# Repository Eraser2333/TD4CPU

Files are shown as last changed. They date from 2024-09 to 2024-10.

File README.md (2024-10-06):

# TD4CPU

淘宝有售噢
[(https://item.taobao.com/item.htm?abbucket=4&id=839364618107)]

套件128比自己打板买零件要划得来噢，10cm*20cm打板5张要75块钱。

成品一个售价248，咨询客服，如果是GitHub或者BiliBili来的有优惠噢。

## 简介
   这一台由74系列数字电路芯片组成的计算机，满足冯·诺依曼提出的计算机的五大基本构件，包括运算器、存储器、输入设备、输出设备和控制器。其核心是一个由10个74芯片构成的4bit CPU，包含了ALU（算术逻辑单元）、ID（指令译码器）、MUX（数据选择器）、PC（程序计数器）、以及寄存器A、B和输出寄存器。
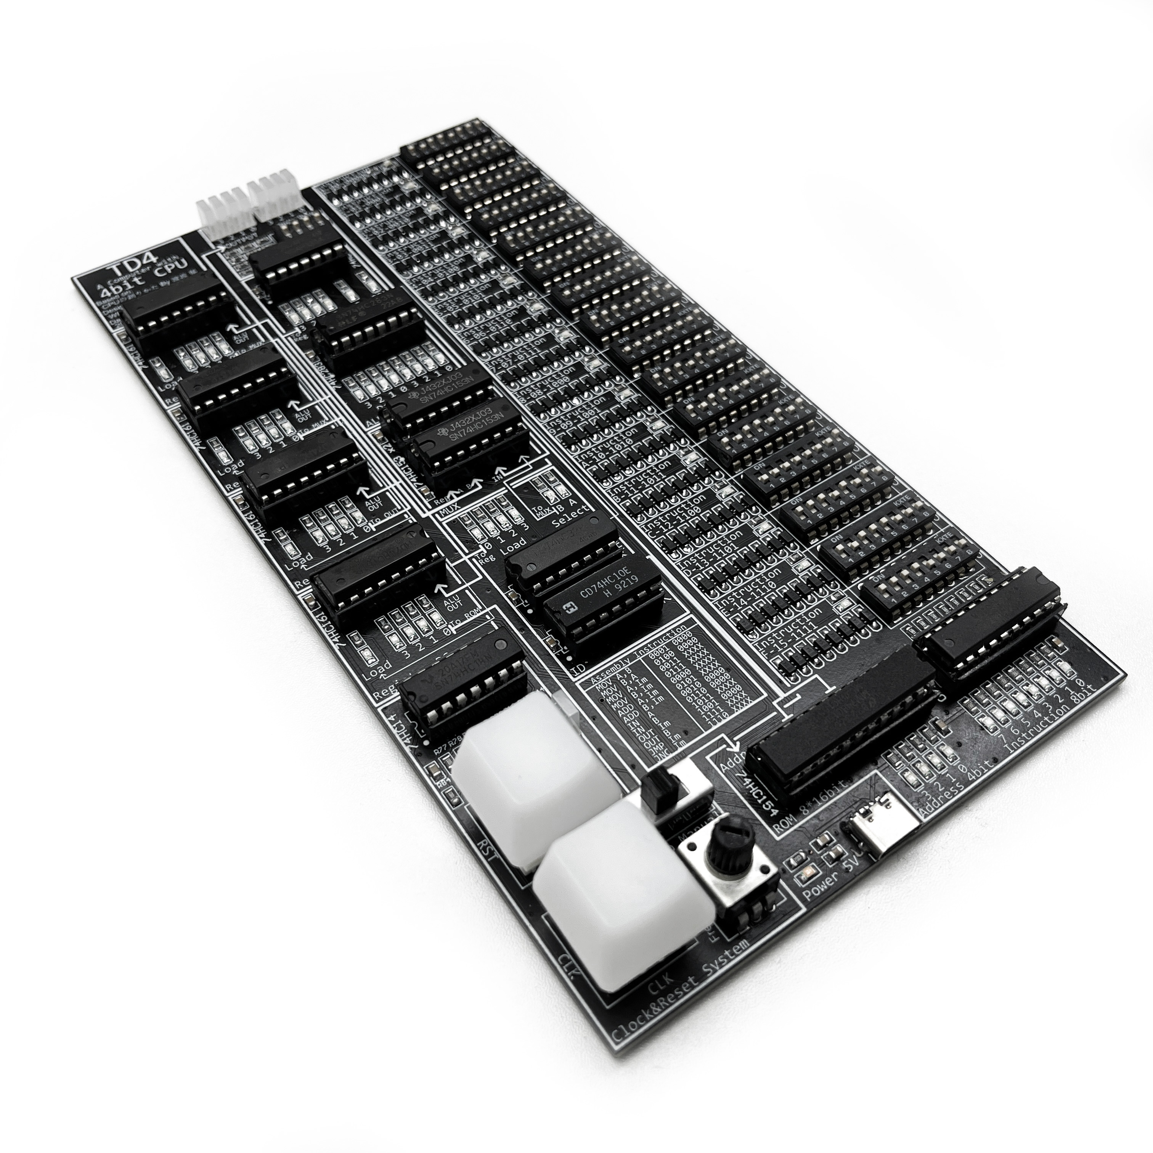
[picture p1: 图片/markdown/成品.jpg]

   与该CPU连接的ROM（只读存储器）用于存储程序，由拨码开关进行编程，可使用12个指令，最多编写16条指令程序。该项目的设计方案来自于日本工程师度波郁（Iku Watanami）的著作《用10个IC轻松介绍CPU设计》，并由来自广州的创元素团队复刻并讲解。由于创元素制复刻的套件不太符合笔者的电路设计审美。故在此基础上制作了更加美观，指示灯清晰的版本。
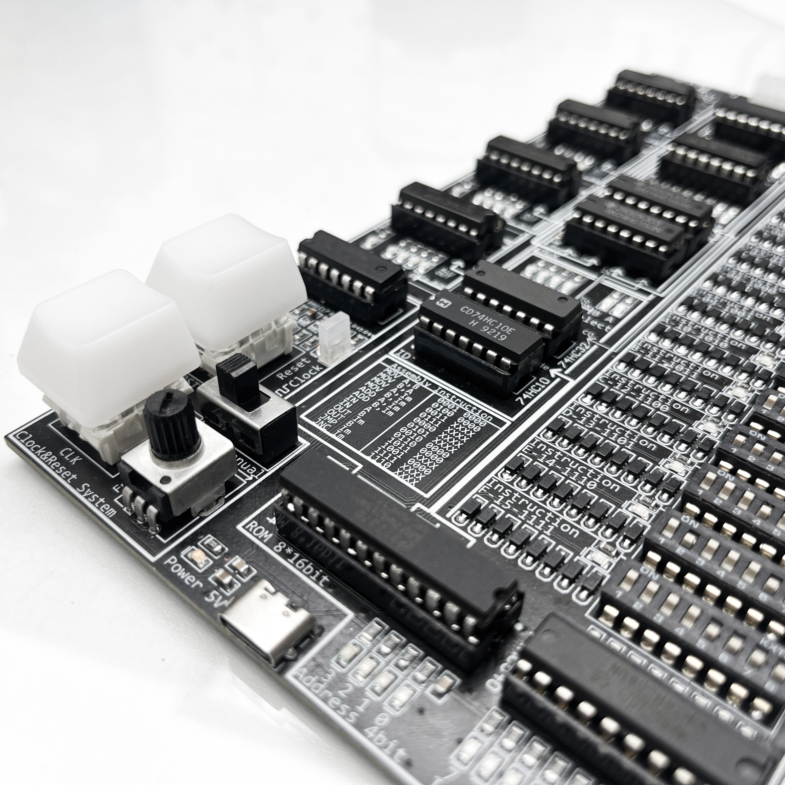
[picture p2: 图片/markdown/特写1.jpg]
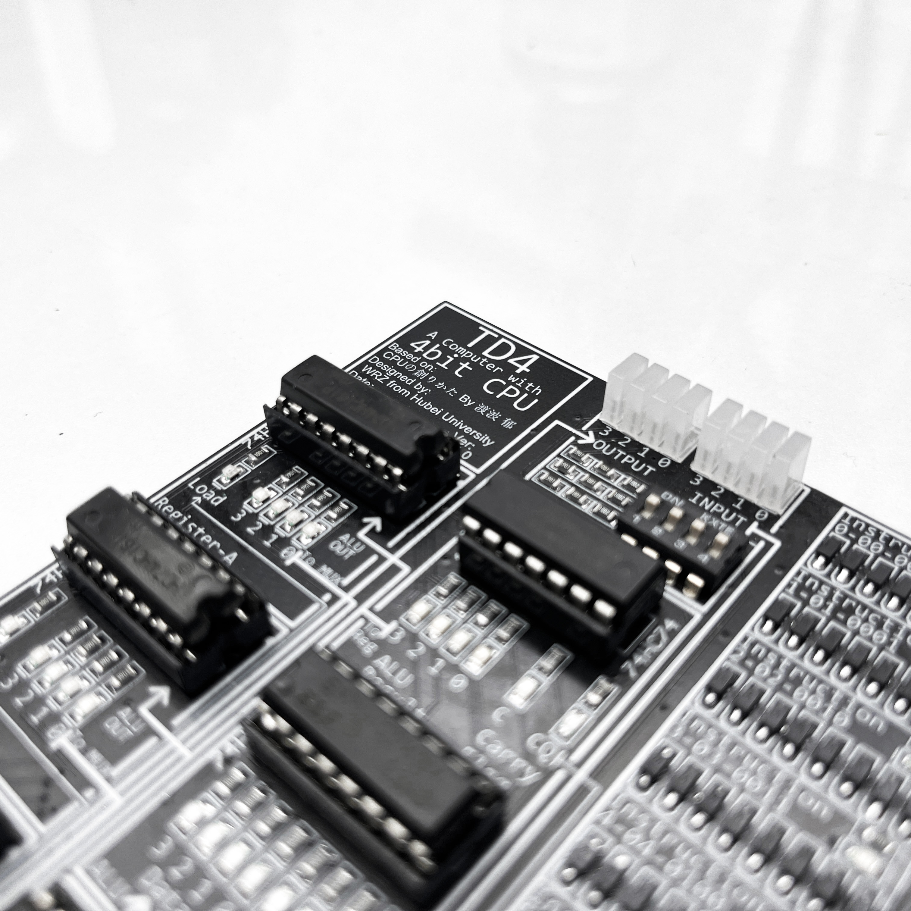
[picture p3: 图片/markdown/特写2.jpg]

<div align=center>
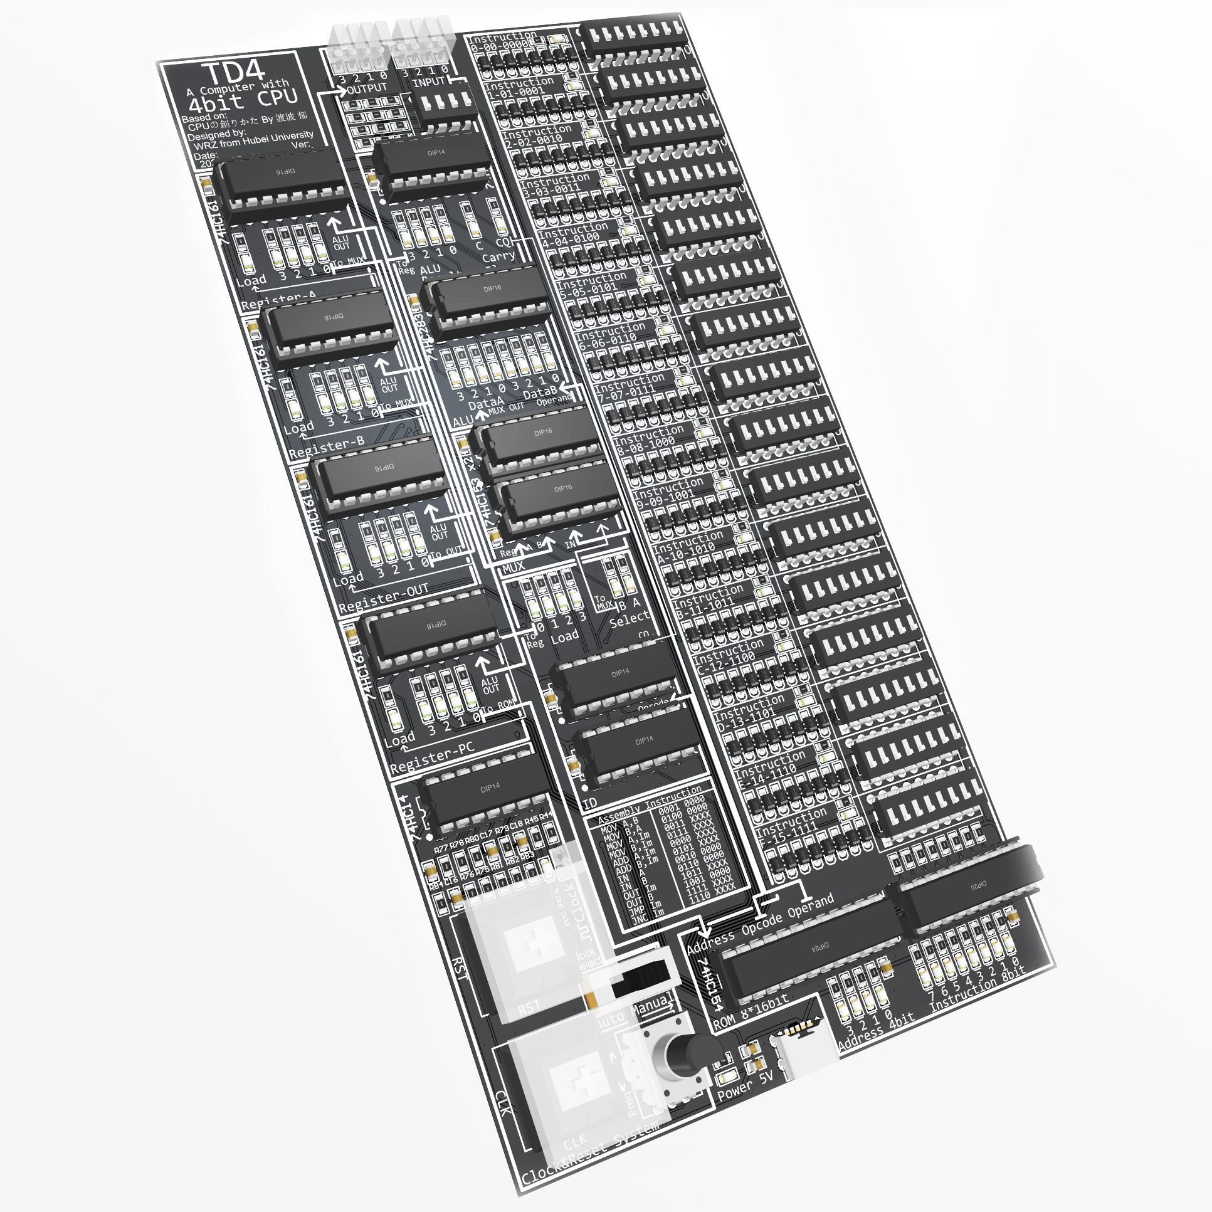
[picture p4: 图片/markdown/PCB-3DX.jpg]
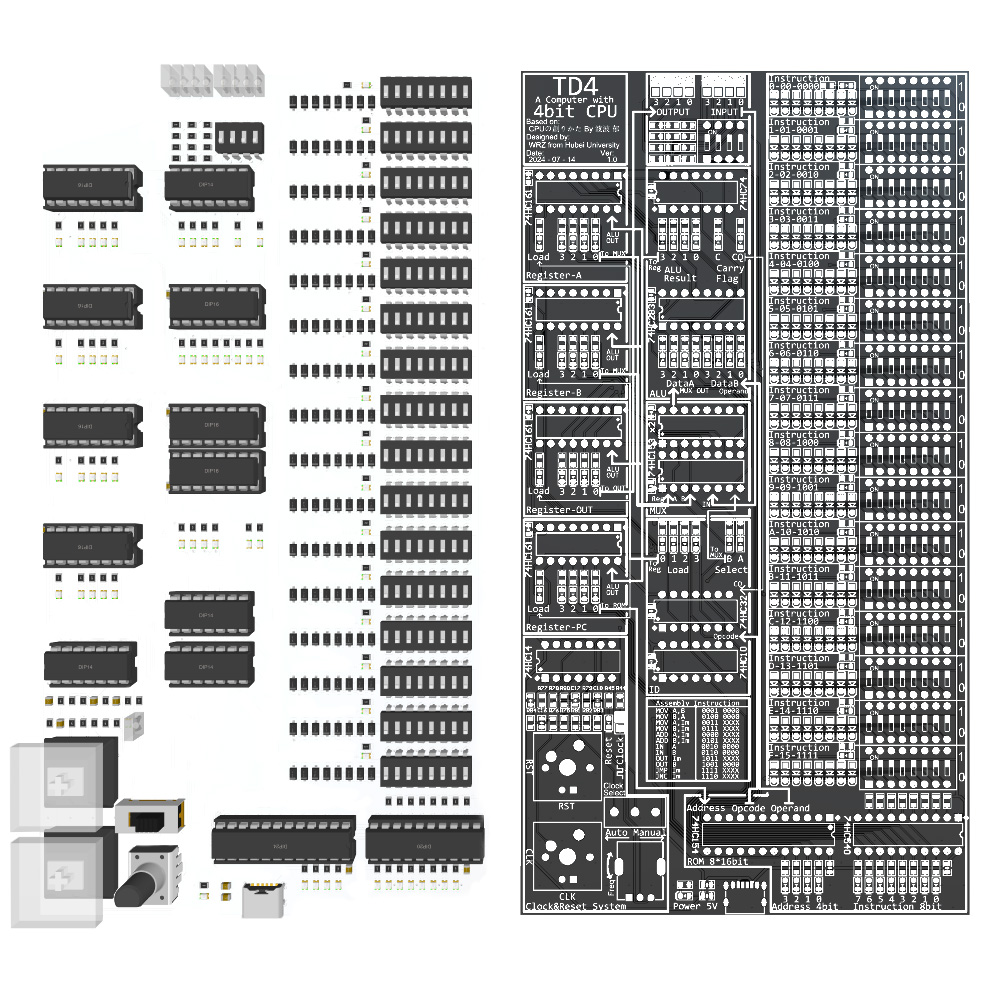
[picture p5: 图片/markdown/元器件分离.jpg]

</div>

## 电路原理介绍
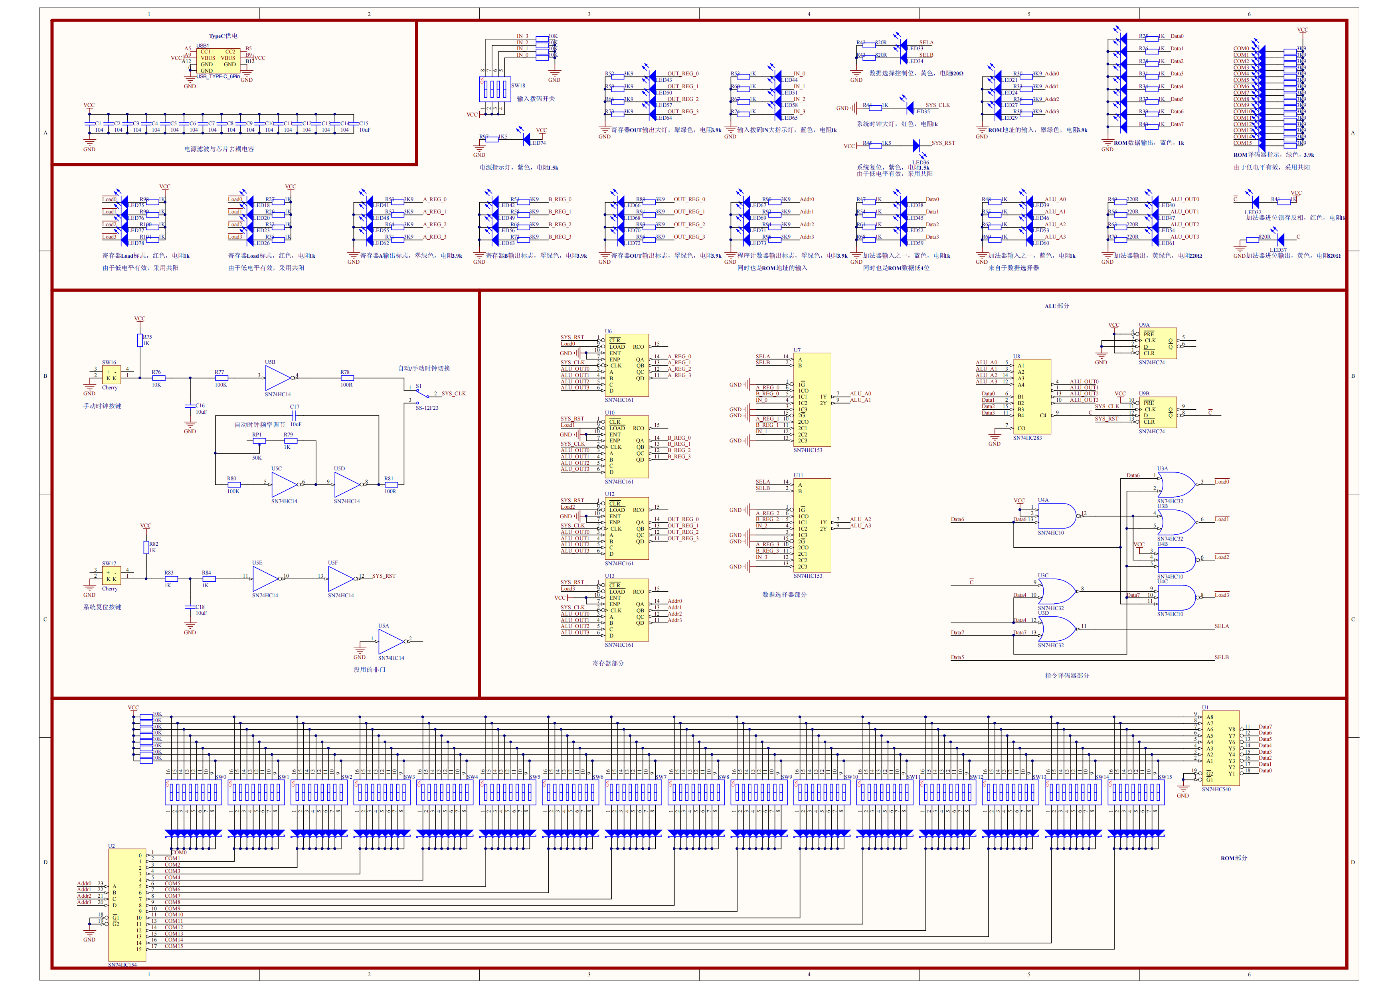
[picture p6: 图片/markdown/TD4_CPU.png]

### CPU部分
CPU部分，原作者度波郁提供了一个网址用于仿真这台计算机：
	https://vanya.jp.net/td4/
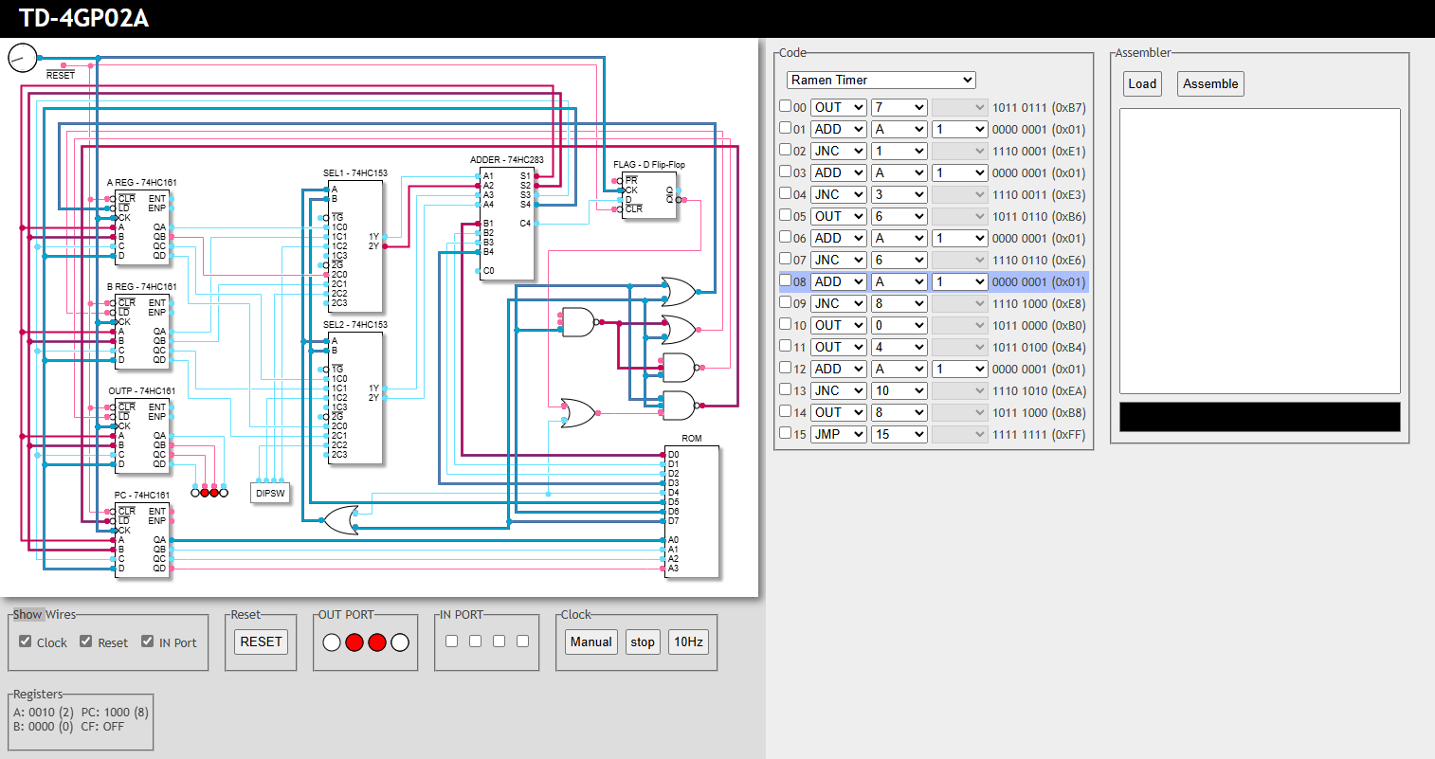
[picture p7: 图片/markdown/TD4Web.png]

其中4片74HC161分别构成了4个Register（寄存器）A，B，OUT，PC，分别用于数据的临时存储、输出以及程序计数器（Program Counter）。
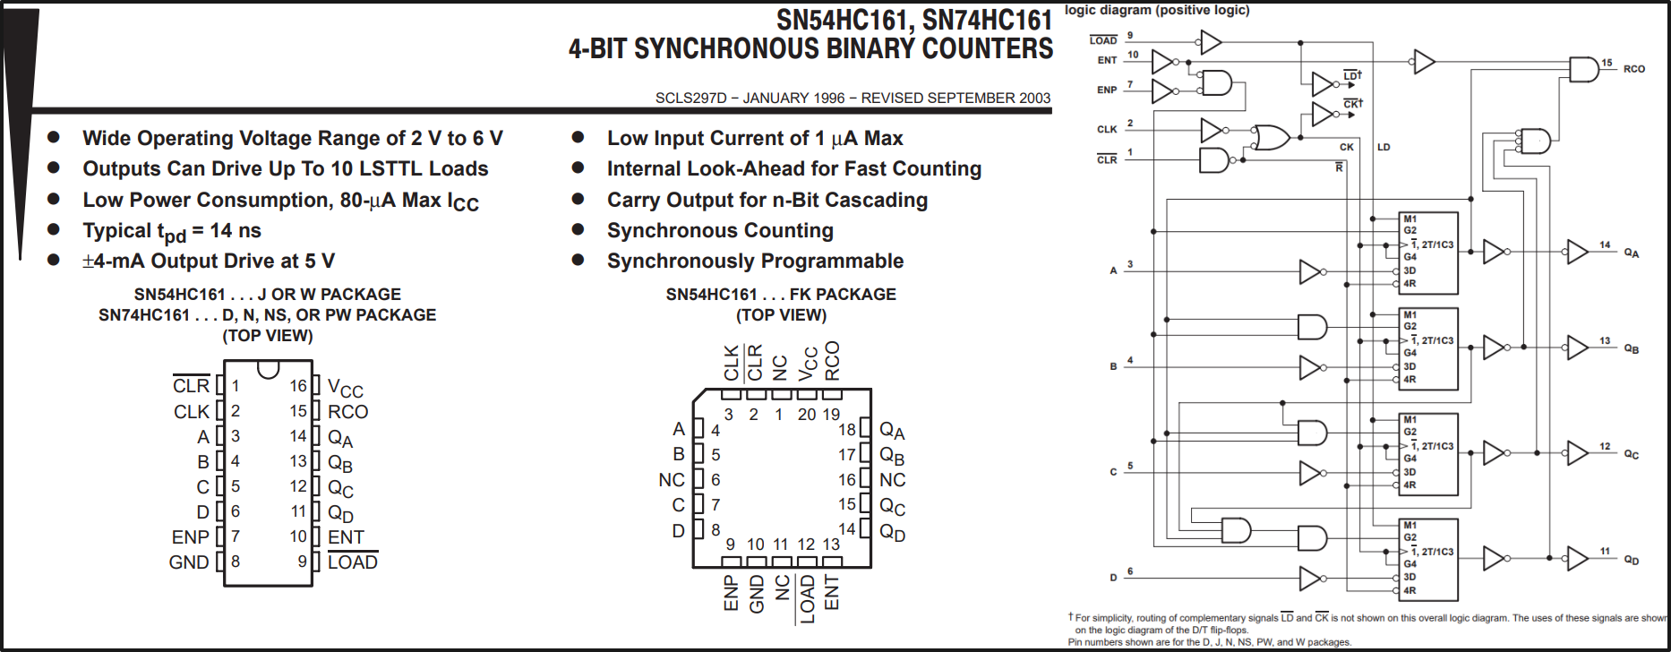
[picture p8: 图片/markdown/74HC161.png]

74HC161是一个4位2进制可预置的同步加法计数器，其中寄存器A、B、OUT仅使用了其预置个功能，即锁存。而寄存器PC还使用了其计数功能用于递增程序地址。锁存受ID模块控制，计数时钟来源于主时钟。

然后有2片74HC153作为MUX（数据选择器），用于选择进入ALU的数据来源。
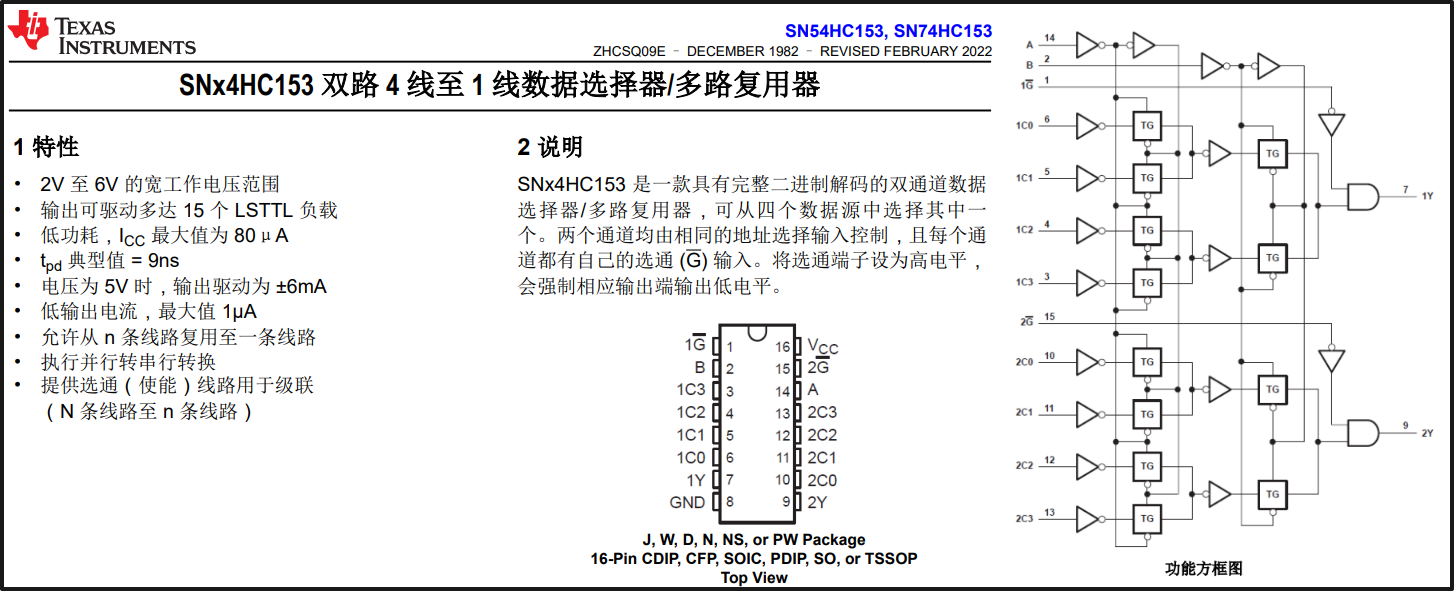
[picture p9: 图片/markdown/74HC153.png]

74HC153是一个2路4选1多路选择器，通过2个进行组合，形成了一个4bit 4选1数据选择器。输入分别接了寄存器A、B、外部输入IN和GND。数据选择受ID控制。

接着是由1片74HC283和1片74HC74构成的ALU（算数逻辑单元），其中283负责运算，将数据选择器送来的4bit数据与指令中的Operand（操作数）相加并得到结果和进位。而74HC74负责锁存进位标志位（Carry Flag）。
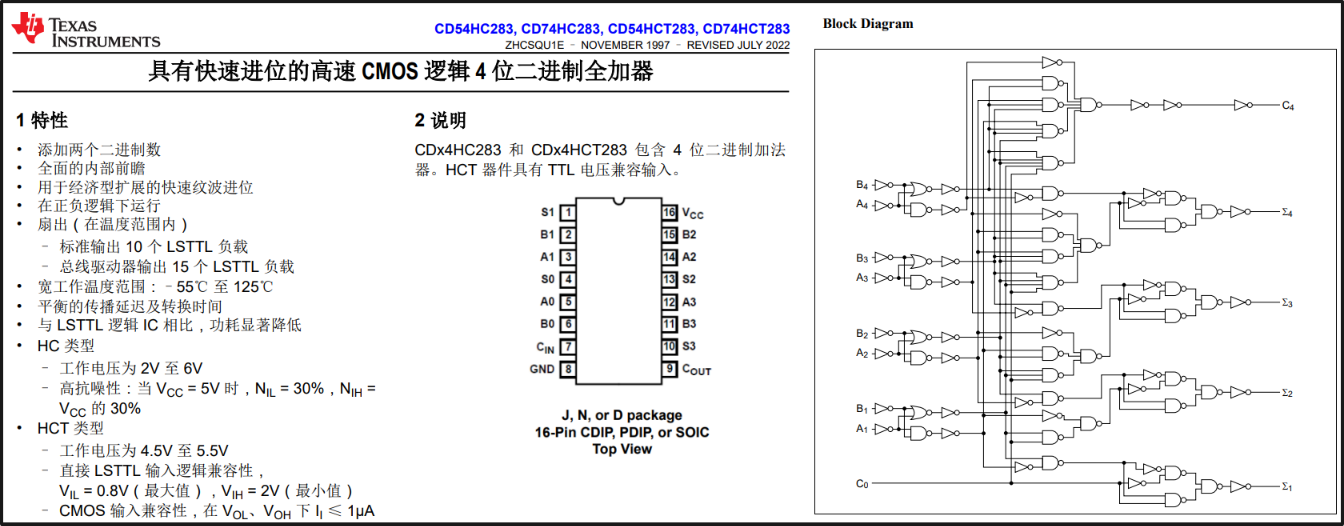
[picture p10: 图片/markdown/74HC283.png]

74HC283是一个4位2进制全加器，可直接得到两个数相加的结果并进位，74HC74是一个双D触发器，在时钟的上升沿锁住进位标志，并可以影响下一条指令的运行。

最后是由1片74HC32和74HC10构成的ID（指令译码器），用于将指令中的Opcode（操作码）译码成对应的操作，通过控制MUX（数据选择器）和4个寄存器的Load，即在时钟来时寄存器是否装载来自ALU的结果。
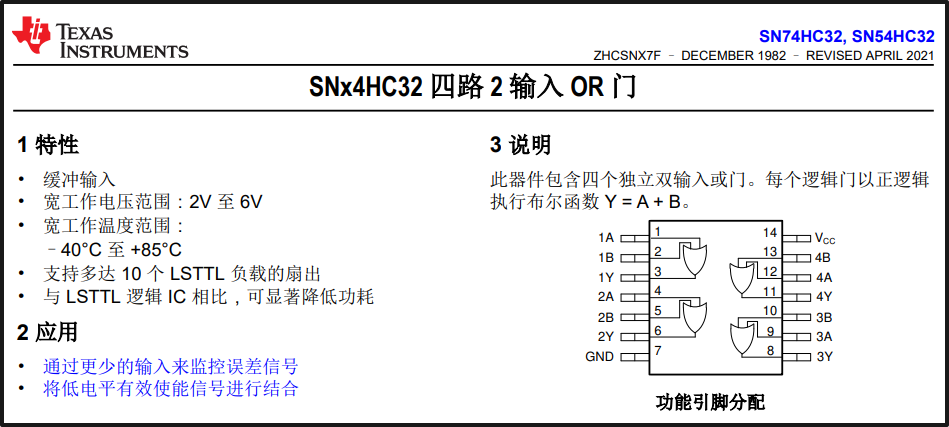
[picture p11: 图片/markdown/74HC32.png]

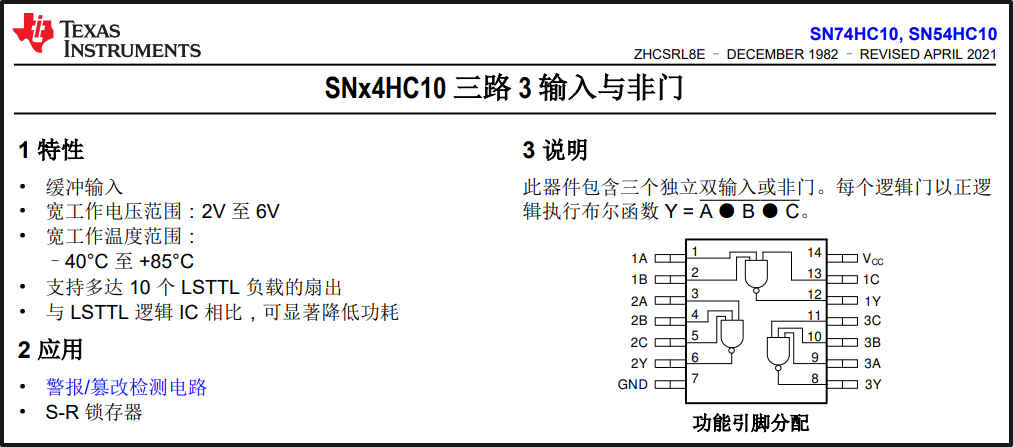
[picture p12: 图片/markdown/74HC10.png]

74HC32是四路2输入或门，74HC10是三路3输入与非门。

### ROM部分
ROM部分，由1片74HC540、1片74HC154、16个8位拨码开关、16*8=128个二极管、以及上拉电阻组成。
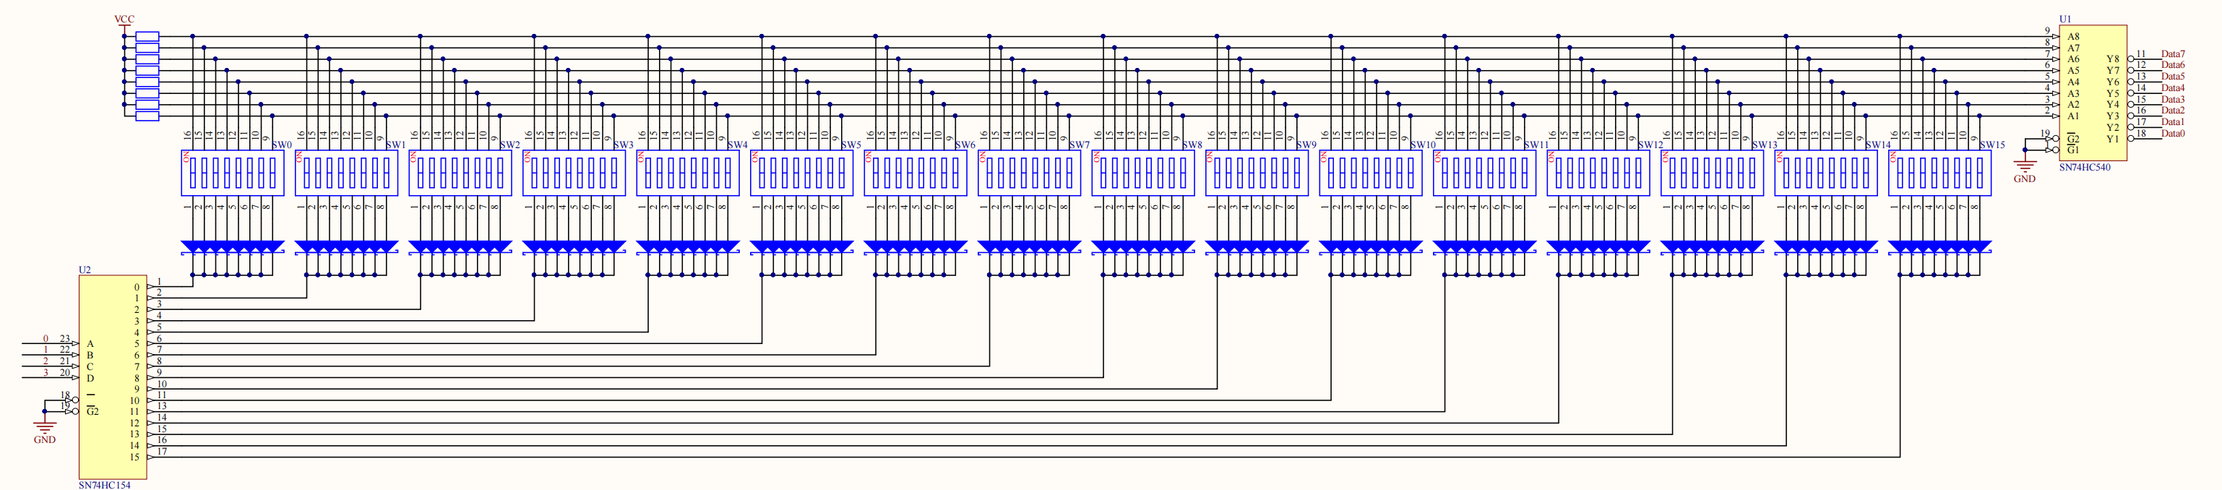
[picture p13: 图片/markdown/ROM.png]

其中由74HC154作为地址译码器，选择对应的拨码开关+二极管组合，即选择了对应的数据。
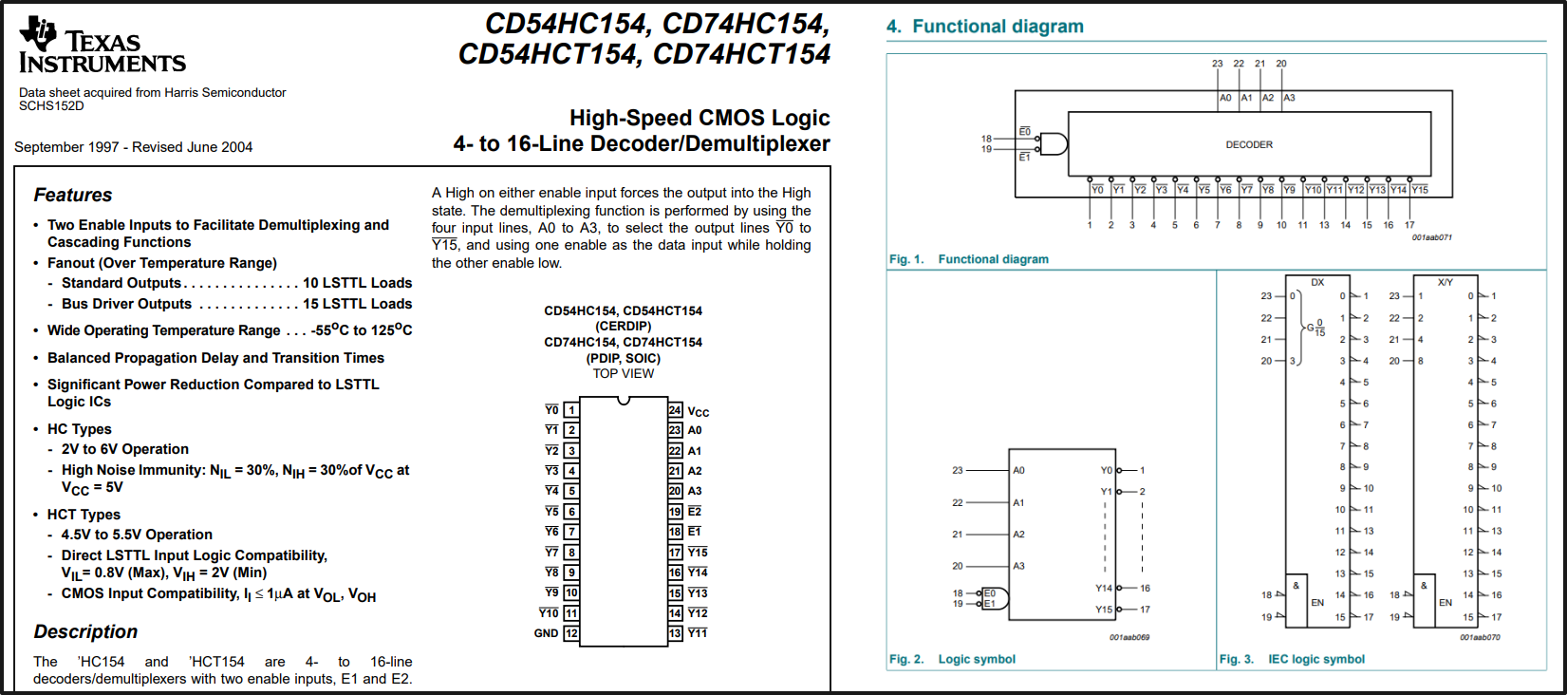
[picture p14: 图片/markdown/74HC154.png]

74HC154是一个4-16线译码器，输入二进制的0~15，对应的一个输出会置低，从而选中拨码开关+二极管组合，如果拨码开关的某位向上，即开关闭合，则使二极管导通，对应的线为低电平；反之拨码开关向下时，由于上拉电阻，对应的数据线则是高电平。

而74HC540用于将数据反相以及增强驱动。
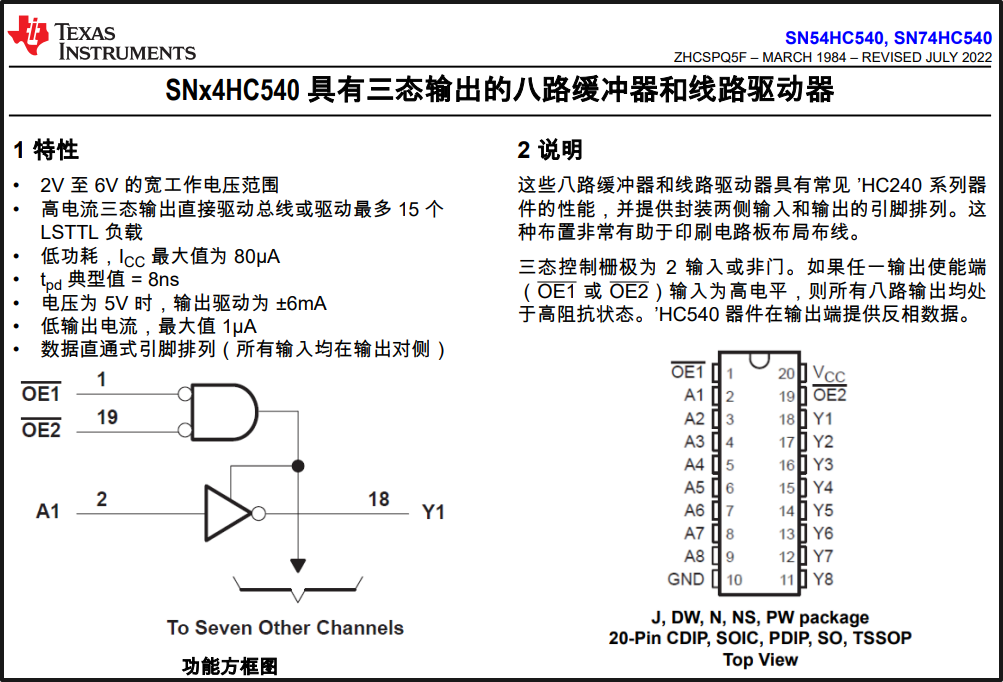
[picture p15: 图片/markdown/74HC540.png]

74HC540是一个反相输出的八路缓冲器，即8个并列的非门由于开关向上是0，向下是1，不符合一般的认知，所以对数据进行反相，同时上拉电阻产生的高电平驱动能力不足（10KΩ上拉电阻），以及经过二极管产生的低电平电位不够低（0.7V左右，肖特基二极管0.5V），所以需要增强数据线的驱动能力。

最后是系统时钟与复位部分。

系统时钟采用了手动、自动时钟两种模式，通过开关切换。
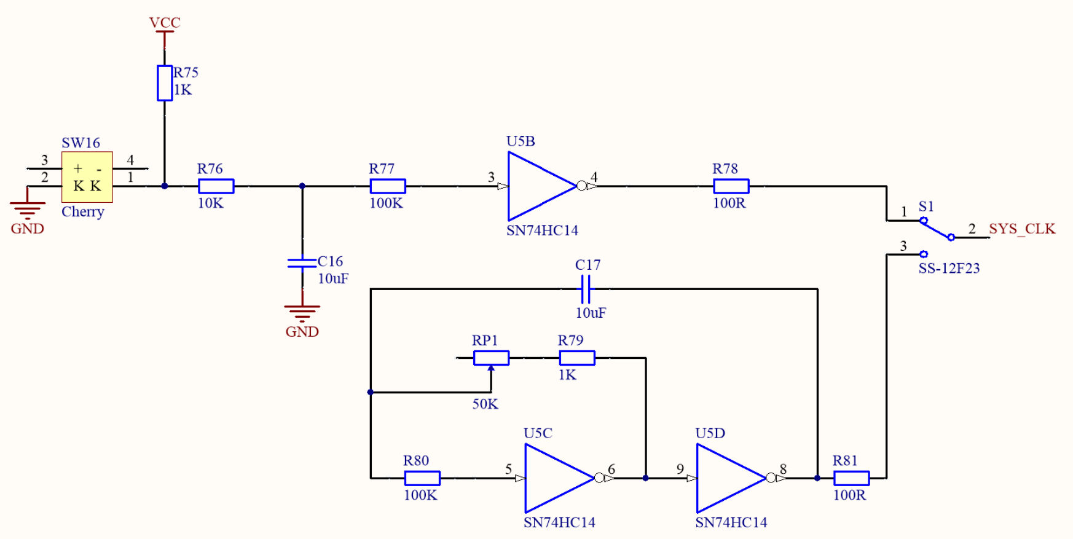
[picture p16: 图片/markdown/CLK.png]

手动模式通过按键按下接地形成低电平，抬起时因为上拉电阻形成高电平。同时通过电容以及施密特触发器74HC14进行消抖。
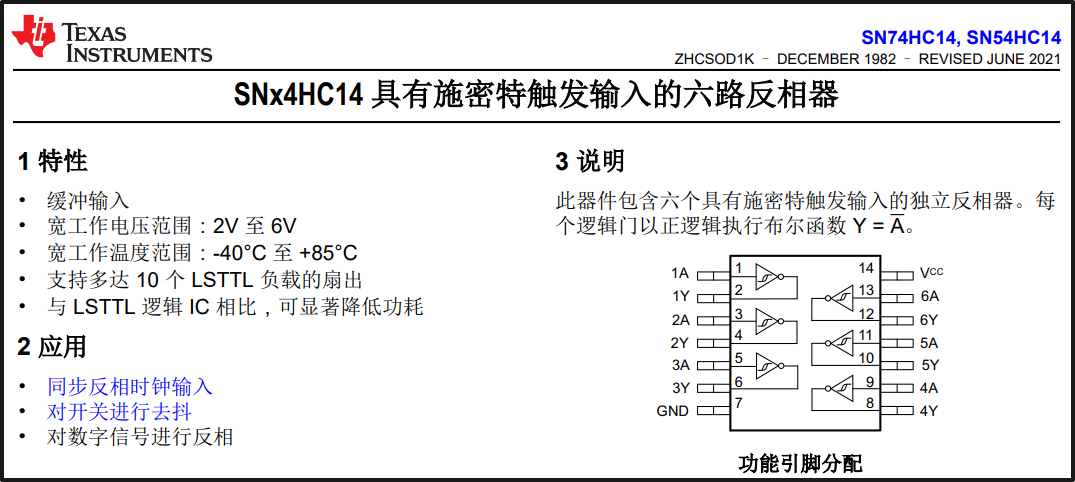
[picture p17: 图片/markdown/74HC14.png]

74HC14是一个六路的具有施密特触发输入的反相器，同时参与了自动时钟的震荡、手动时钟的消抖、复位的消抖和反相等多个电路。

自动时钟采用了一种门电路组成的多谐振荡器，通过RC电路充放电形成震荡。同时，通过调节电位器的值可以更改振荡频率。

复位电路与手动时钟电路差不多，只是多了个反相。
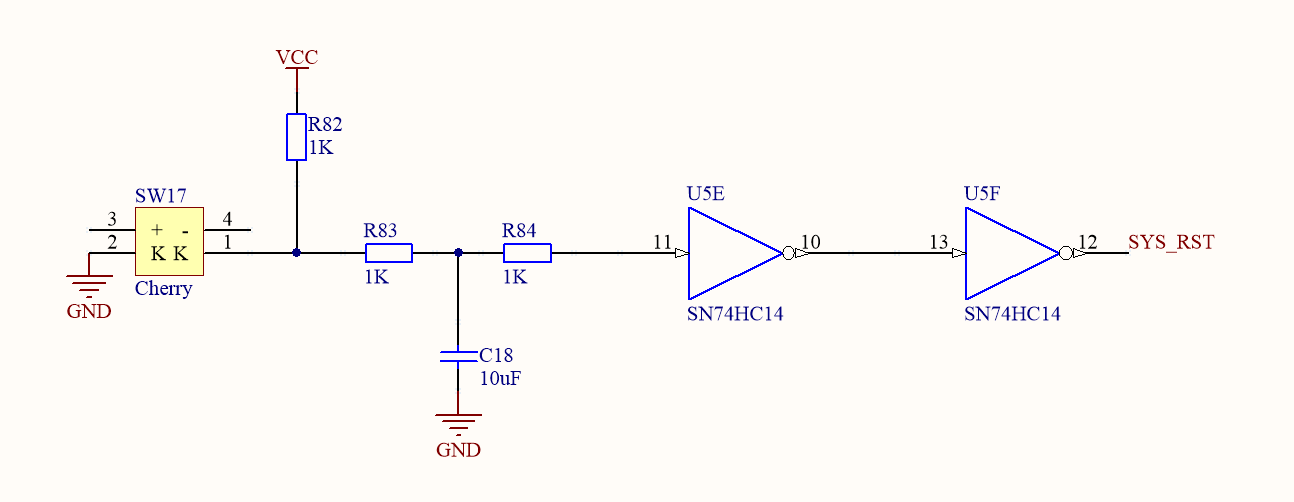
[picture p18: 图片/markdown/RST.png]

这套电路一共用了74HC14的5个反相器，剩一个没用。

## 指令集

TD4 中定义了十二种类型的指令，这里汇总了所有指令的列表。

由于TD4为4bitCPU，所以每条指令都由4bit的Opcode（操作码）和4bit的Operand（操作数）组成，一共8bit。这里用多种汇编助记符表示

| 助记符 | 指令 | 解释 | 
| --- | --- | --- |
| MOV A,B | 0001 0000 | 将 B 寄存器传送到寄存器A。不受C标志影响，执行后C标志置0。 | 
| MOV B,A|0100 0000|将 A 寄存器转移到寄存器B。不受C标志影响，执行后C标志置0。| 
| MOV A,Im | 0011 XXXX | 将立即数XXXX传送到寄存器A。不受C标志影响，执行后C标志置0。 | 
| MOV B,Im | 0111 XXXX | 将立即数XXXX传送到寄存器B。不受C标志影响，执行后C标志置0。 | 
| ADD A,Im | 0000 XXXX | 将立即数XXXX累加到寄存器A。不受C标志影响，执行后发生进位C标志置1。 | 
| ADD B,Im | 0101 XXXX | 将立即数XXXX累加到寄存器B。不受C标志影响，执行后发生进位C标志置1。 | 
| IN A | 0010 0000 | 将输入端口数据传输到寄存器A。不受C标志影响，执行后C标志置0。 | 
| IN B | 0110 0000 | 将输入端口数据传输到寄存器B。不受C标志影响，执行后C标志置0。 | 
| OUT Im	 | 1011 XXXX | 将立即数XXXX传输到输出端口。不受C标志影响，执行后C标志置0。 | 
| OUT B | 1001 0000 | 将寄存器B传输到输出端口。不受C标志影响，执行后C标志置0。 | 
| JMP Im | 1111 XXXX | 程序跳转到立即数指示的地址XXXX。不受C标志影响，执行后C标志置0。 | 
| JNC | 1110 XXXX | 当C标志为0时，程序跳转到立即数所指示的地址。反之什么都不做。执行后C标志置0。 | 

## PCB
PCB采用双层板结构，板材为FR-4。
PCB尺寸为19.2cm x 10.2cm，板厚1.6mm，铜厚1oz。
其他工艺：哑黑色阻焊，白色字符，有铅喷锡，过孔盖油。
最小线宽：5mil，最小孔径：0.5mm。
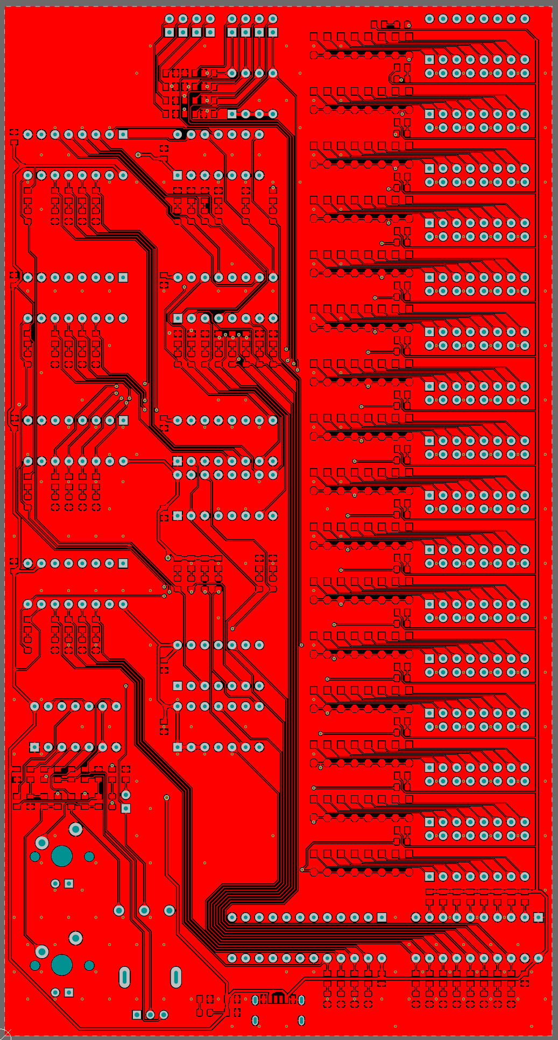
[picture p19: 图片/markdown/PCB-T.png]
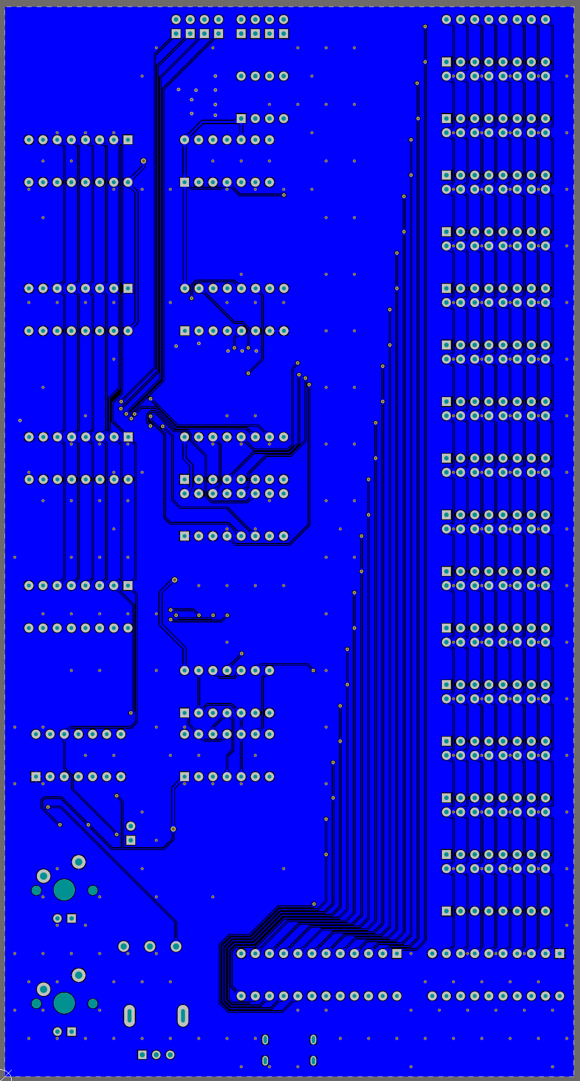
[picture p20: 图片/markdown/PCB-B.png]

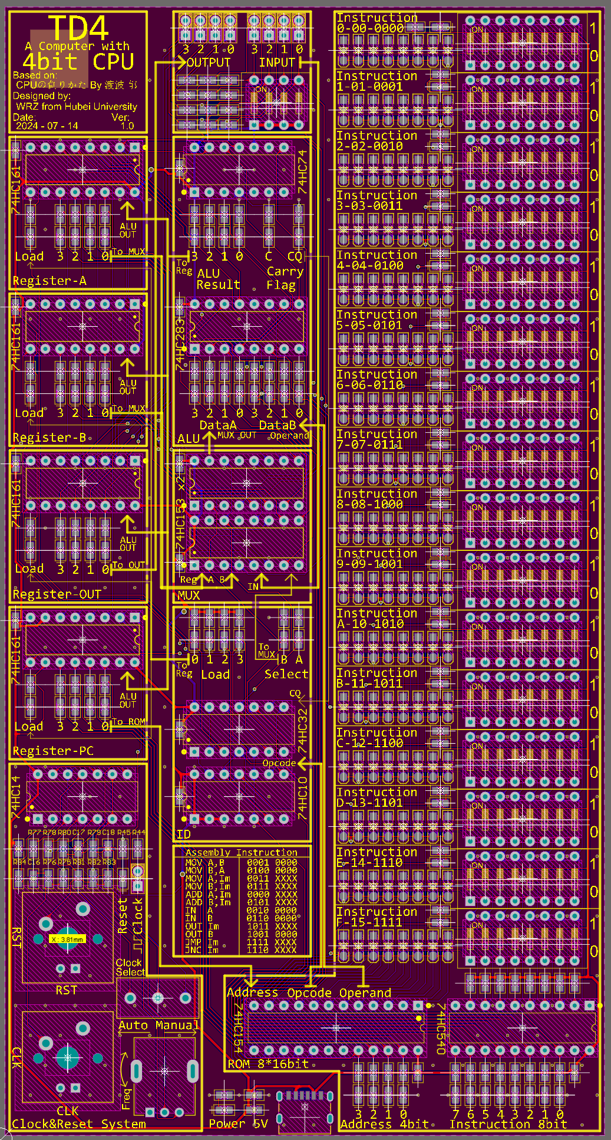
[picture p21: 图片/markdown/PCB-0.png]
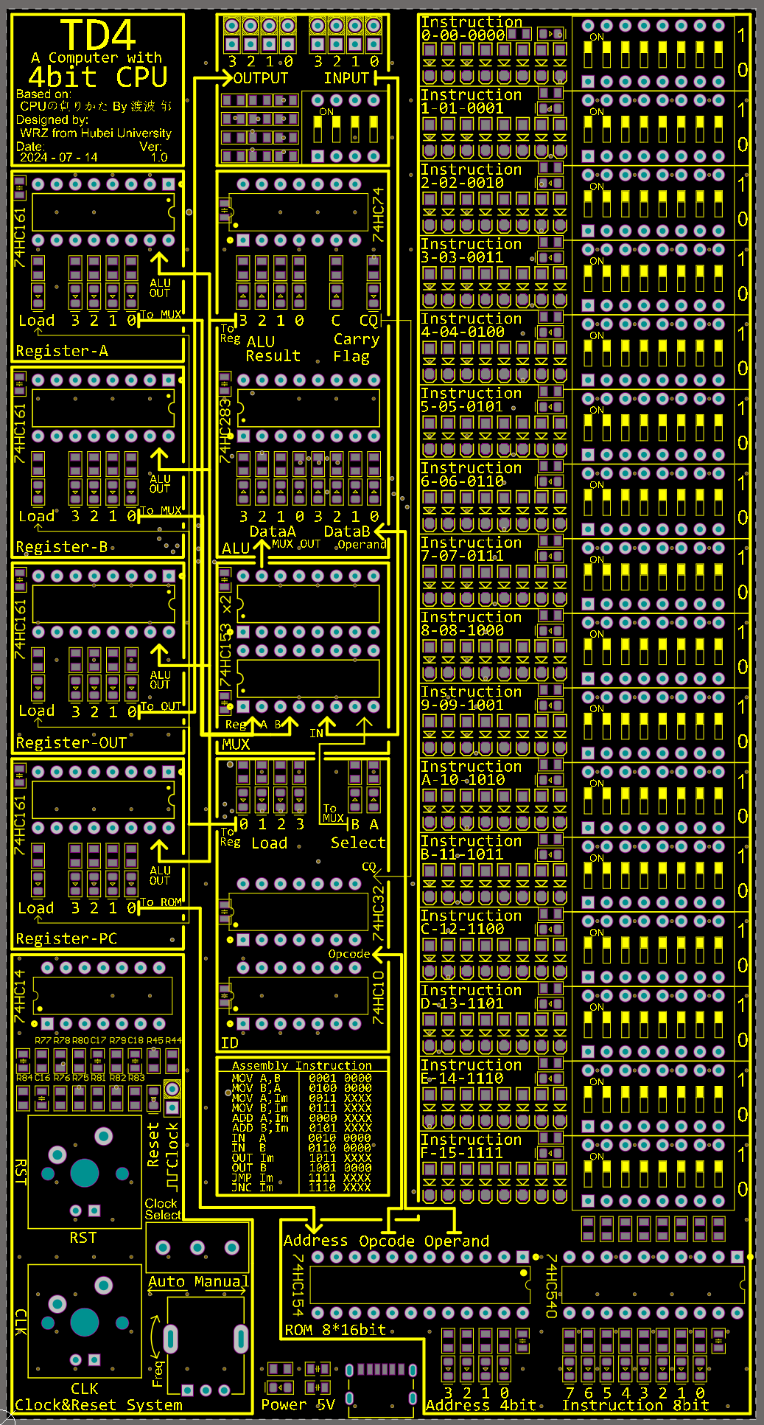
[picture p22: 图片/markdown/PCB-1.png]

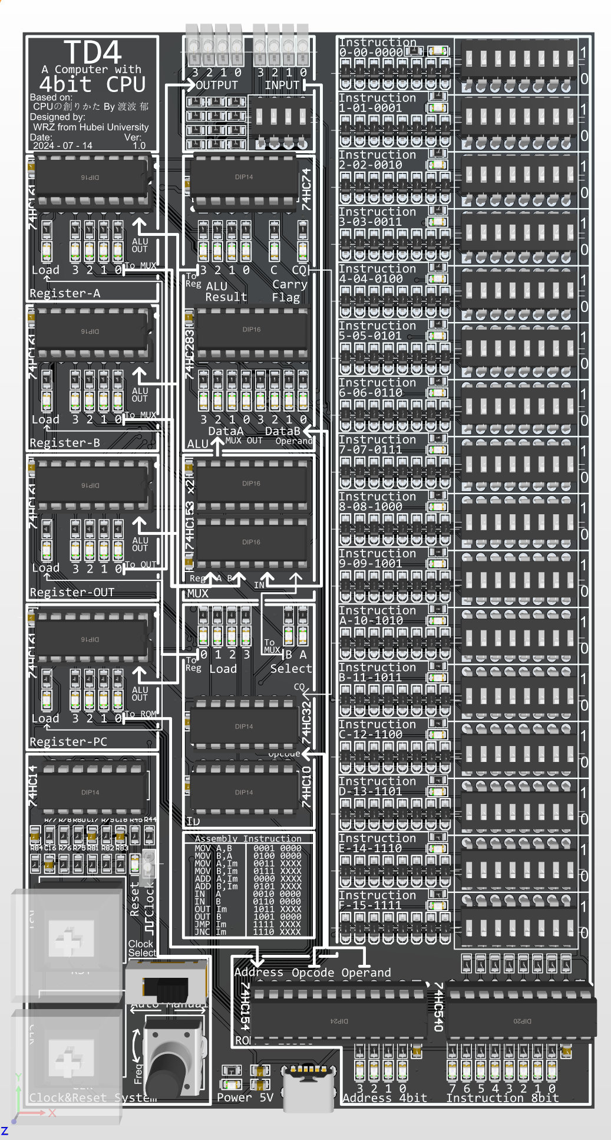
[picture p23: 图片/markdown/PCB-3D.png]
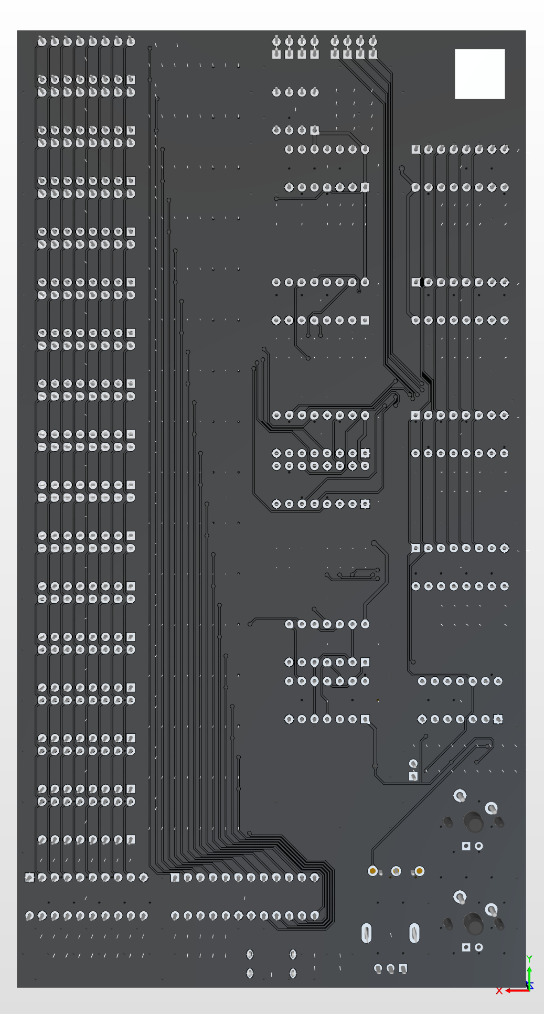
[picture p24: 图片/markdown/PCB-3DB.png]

<div align=center>
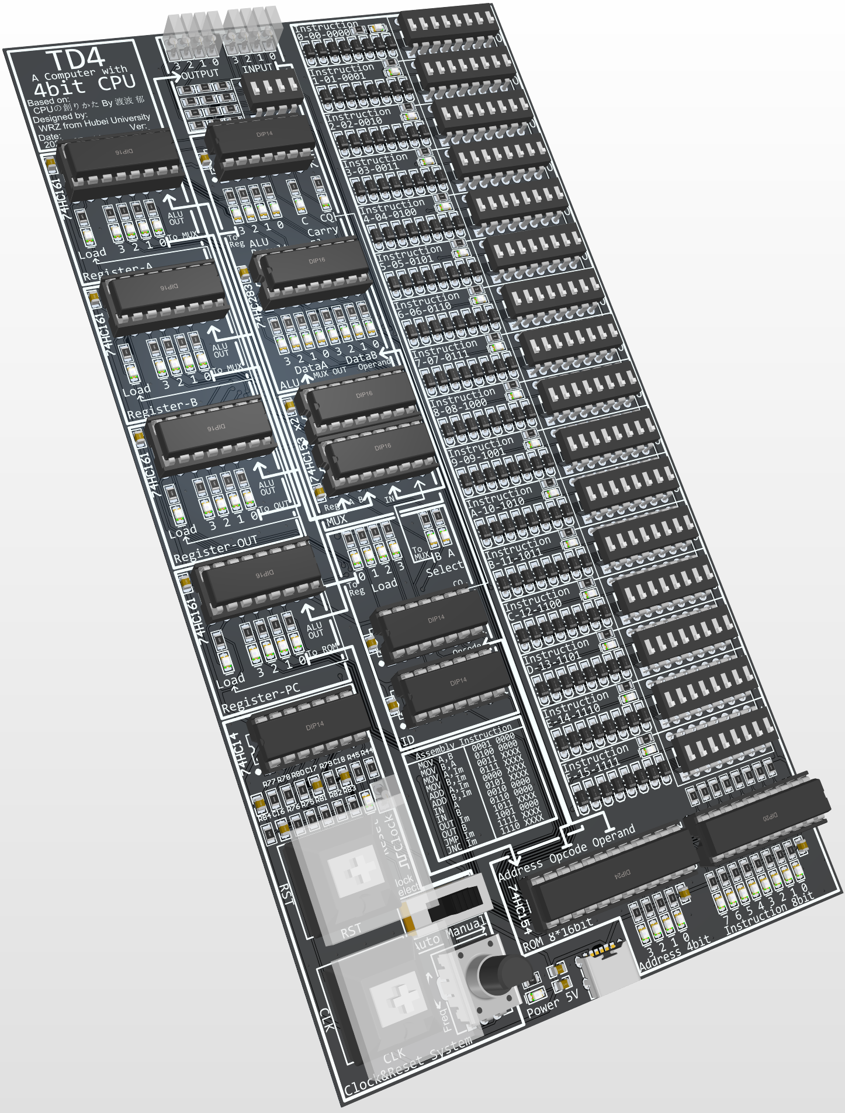
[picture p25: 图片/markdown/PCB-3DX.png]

</div>

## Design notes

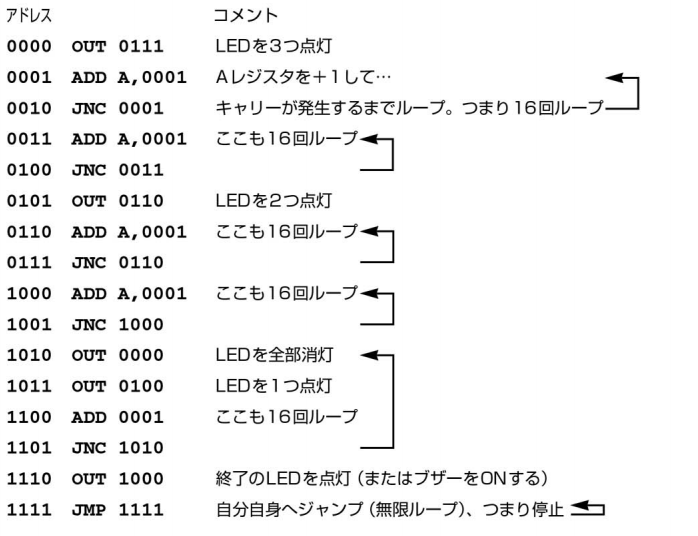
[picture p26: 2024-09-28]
图片/示例程序.png

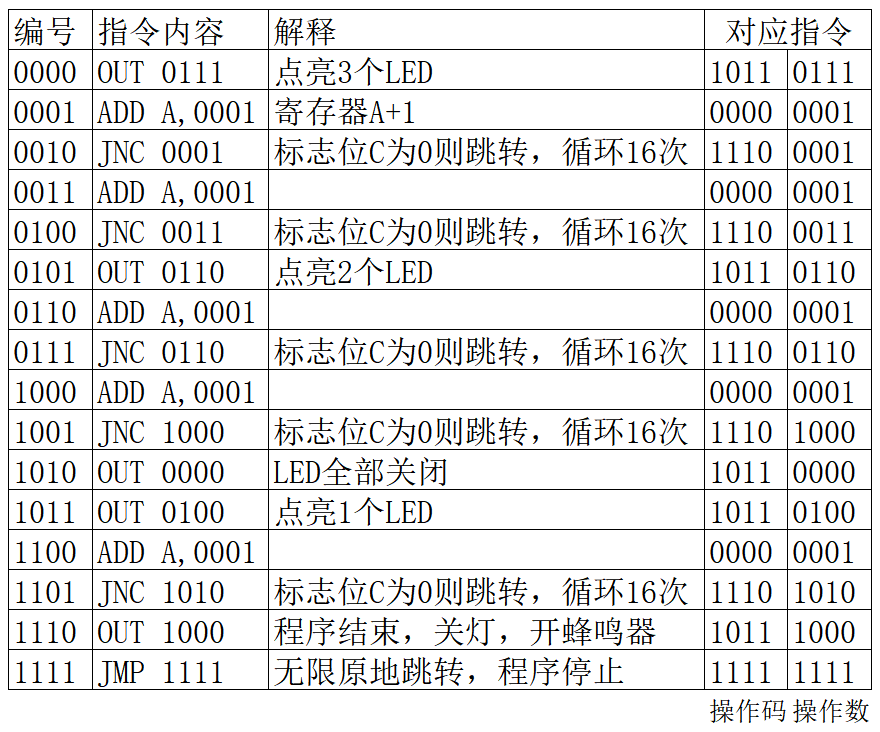
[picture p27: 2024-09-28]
图片/示例程序翻译.png

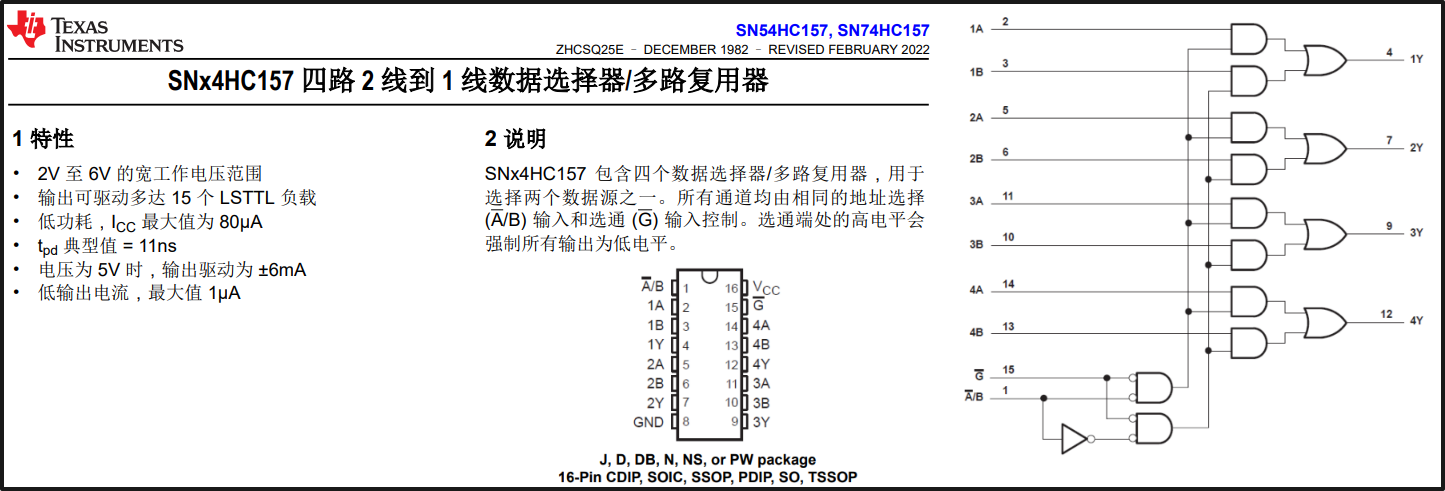
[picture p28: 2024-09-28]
图片/markdown/74HC157.png

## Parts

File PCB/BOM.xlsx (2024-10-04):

TD4材料清单
序号 | 元件名 | 描述 | 标号 | 封装 | 标识 | 数量 | 实际 | 冗余 | 核对
1 | 104 | 贴片电容100nF | C1~C14 | 0805 | 104 | 14 | 15 | 1
2 | 106 | 贴片电容10uF | C15~C18 | 0805 | 106 | 4 | 5 | 1
3 | SS14 | 肖特基二极管 | D1~D128 | SOD-123 | D | 128 | 140 | 12
4 | 绿色 | 贴片LED | LED0, LED1, LED2, LED3, LED4, LED5, LED6, LED7, LED8, LED9, LED10, LED11, LED12, LED13, LED14, LED15, LED21, LED24, LED27, LED29, LED41, LED42, LED48, LED49, LED55, LED56, LED62, LED63, LED66, LED67, LED68, LED69, LED70, LED71, LED72, LED73 | LED0805 | G | 36 | 40 | 4
5 | 蓝色 | 贴片LED | LED16, LED17, LED19, LED22, LED25, LED28, LED30, LED31, LED38, LED39, LED46, LED53, LED60, LED45, LED52, LED59 | LED0805 | B | 16 | 20 | 4
6 | 红色 | 贴片LED | LED18, LED20, LED23, LED26, LED32, LED75, LED76, LED77, LED78 | LED0805 | R | 9 | 10 | 1
7 | 黄色 | 贴片LED | LED33,34,37 | LED0805 | Y | 3 | 4 | 1
8 | 紫色 | 贴片LED | LED36,74 | LED0805 | P | 2 | 3 | 1
9 | 黄绿色 | 贴片LED | LED40,47,54,61 | LED0805 | YG | 4 | 5 | 1
10 | 3K9 | 贴片电阻 | R9, R10, R11, R12, R13, R14, R15, R16, R17, R18, R19, R20, R21, R22, R23, R24, R30, R33, R36, R38, R50, R51, R52, R57, R58, R59, R64, R65, R66, R71, R72, R73, R89, R90, R91, R92, R93, R94, R95, R96 | R0805_L | 3K9 | 40 | 45 | 5
11 | 1K | 贴片电阻 | R25, R26, R27, R28, R29, R31, R32, R34, R35, R37, R39, R40, R41, R44, R47, R48, R53, R54, R55, R60, R61, R62, R67, R68, R69, R74, R75, R79, R82, R83, R84, R98, R99, R100, R101，R45, R97 | R0805_L | 1K | 37 | 40 | 3
12 | 10K | 贴片电阻 | R1, R2, R3, R4, R5, R6, R7, R8, R76, R85, R86, R87, R88 | R0805_L | 10K | 13 | 15 | 2
13 | 220R | 贴片电阻 | R49,56,63,70 | R0805_L | 220 | 4 | 5 | 1
14 | 820R | 贴片电阻 | R42, R43, R46 | R0805_L | 820 | 3 | 4 | 1
15 | 100K | 贴片电阻 | R77, R80 | R0805_L | 100K | 2 | 3 | 1
16 | 100R | 贴片电阻 | R78, R81 | R0805_L | 100 | 2 | 3 | 1
17 | TYPE-C_6Pin | USB_TYPE-C_6Pin母座 | USB1 | USB-C-SMD_6P | USB | 1 | 2 | 1
18 | 红色 | 直插LED | LED35 | LED F257-R | REG | 1 | 1 | 0
19 | 绿色 | 直插LED | LED43,50,57,64 | LED F257-G | GREEN | 4 | 4 | 0
20 | 蓝色 | 直插LED | LED44,51,58,65 | LED F257-B | BLUE | 4 | 4 | 0
21 | 50K | 单联电位器 | RP1 | XV09223NPV-20F | Rp | 1 | 1 | 0
22 | SS-12F23 | 1路波动开关 | S1 | SS-12D10 | SWITCH | 1 | 1 | 0
23 | DIP-SW-8P | 8路编码开关 | SW0~SW15 | SW DIP-8P-B | - | 16 | 16 | 0
24 | DIP-SW-4P | 4路编码开关 | SW18 | SW DIP-4P-B | - | 1 | 1 | 0
25 | Cherry | 带灯机械按键开关 | SW16, SW17 | DIP-CHERRY-Hat | KEY | 2 | 2 | 0
26 | SN74HC540 | 反相输出的八路缓冲器 | U1 | DIP20-300_MH | 74HC540 | 1 | 1 | 0
27 | SN74HC154 | 4-16线译码器 | U2 | DIP24-300_MH | 74HC154 | 1 | 1 | 0
28 | SN74HC32 | 四路2输入或门 | U3 | DIP14-300_MH | 74HC32 | 1 | 1 | 0
29 | SN74HC10 | 三路3输入与非门 | U4 | DIP14-300_MH | 74HC10 | 1 | 1 | 0
30 | SN74HC14 | 六路施密特反相器 | U5 | DIP14-300_MH | 74HC14 | 1 | 1 | 0
31 | SN74HC161 | 4位2进制加法计数器 | U6,10,12,13 | DIP16-300_MH | 74HC161 | 4 | 4 | 0
32 | SN74HC153 | 2路4选1多路选择器 | U7, U11 | DIP16-300_MH | 74HC153 | 2 | 2 | 0
33 | SN74HC283 | 4位2进制全加器 | U8 | DIP16-300_MH | 74HC283 | 1 | 1 | 0
34 | SN74HC74 | 双D触发器 | U9 | DIP14-300_MH | 74HC74 | 1 | 1 | 0
35 | 14Pin | IC座 | - | - | - | 4 | 4 | 0
36 | 16Pin | IC座 | - | - | - | 7 | 7 | 0
37 | 20Pin | IC座 | - | - | - | 1 | 1 | 0
38 | 24Pin | IC座 | - | - | - | 1 | 1 | 0
39 | PCB | 19.2cm x 10.2cm | - | - | - | 1 | 1 | 0
40 | 键帽 | 磨砂透光键帽 | - | - | - | 2 | 2 | 0
